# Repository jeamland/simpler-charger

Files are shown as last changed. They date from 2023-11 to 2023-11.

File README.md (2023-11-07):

# A "Simpler"[^1] Charger

This is a two-port USB charger design based around the [Texas Instruments TPS25858-Q1](https://www.ti.com/product/TPS25858-Q1) controller. It's designed to be part of a larger project to build some charging infrastructure into a shelf, hence the terminal block connections rather than actual USB-C ports. Input power is intended to be 15V coming from a power brick and the intent is to have several of these providing something like 12 ports in total (so 6 completed boards).

A lot of the layout and component selection was "inspired" by [TI's Evaluation Kit](https://www.ti.com/tool/TPS25858Q1EVM-140) for this device, but I have deviated in a few places, mainly for cost reasons. I ~~hope~~think I've validated that these changes are ok.

Full KiCad files, including custom symbols and footprints, are in here along with datasheets, PDF versions of the schematic and PCB layout, and the bill of materials.

[^1]: The original design I made did the full USB-C thing up to 60W and required an actual microcontroller. I may still make that one but, well, I figured I should overcomplicate things in stages.

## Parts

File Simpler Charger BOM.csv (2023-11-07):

Reference | Value | Description | Manufacturer | Manufacturer Part No | Qty
C1, C2 | 1µF 6.3V | CAP CER 1UF 6.3V X7R 0603 | Samsung Electro-Mechanics | CL10B105KQ8NFNC | 2
C3, C15 | 2.2µF | CAP CER 2.2UF 16V X5R 0603 | Kyocera AVX | KGM15AR51C225MT | 2
C4 | 10µF 50V | CAP CER 10UF 50V X7R 1210 | Murata Electronics | GRM32ER71H106MA12L | 1
C5 | 100µF 35V | CAP ALUM 100UF 20% 35V RADIAL | Rubycon | 35ZLJ100M6.3X11 | 1
C6-C8 | 10µF 50V | CAP CER 10UF 50V X5R 1206 | Murata Electronics | GRT31CR61H106KE01L | 3
C9 | 0.1µF 50V | CAP CER 0.1UF 50V X7R 1206 | Samsung Electro-Mechanics | CL31B104KBCNFNC | 1
C10, C14, C16 | 0.1µF 50V | CAP CER 0.1UF 50V X7R 0603 | Samsung Electro-Mechanics | CL10B104KB8NFNC | 3
C11-C13 | 22µF 10V | CAP CER 22UF 10V X7R 0805 | Murata Electronics | GRM21BZ71A226ME15L | 3
J1 | POWER | TERM BLK 2P TOP ENTRY 2.5MM PCB | Phoenix Contact | 1770953 | 1
J2 | PORT_A | TERM BLK 6P TOP ENTRY 2.5MM PCB | Phoenix Contact | 1770995 | 1
J3 | PORT_B | TERM BLK 6P TOP ENTRY 2.5MM PCB | Phoenix Contact | 1770995 | 1
L1 | 1µH | FIXED IND 1UH 12A 10 MOHM SMD | Pulse Electronics | BMRA000606301R0MA1 | 1
L2 | 3.3µH | FIXED IND 3.3UH 20.2A 5.44 MOHM | Vishay Dale | IHLP5050FDER3R3M51 | 1
R1 | 49.9KΩ | RES SMD 49.9K OHM 1% 1/10W 0603 | Panasonic Electronic Components | ERJ-3EKF4992V | 1
R2 | 20KΩ | RES SMD 20K OHM 5% 1/10W 0603 | Vishay Dale | CRCW060320K0JNEA | 1
R3, R6 | 5.1KΩ | RES 5.1K OHM 5% 1/10W 0603 | Vishay Dale | CRCW06035K10JNEAC | 2
R4 | 15KΩ | RES SMD 15K OHM 0.5% 1/10W 0603 | YAGEO | RT0603DRE0715KL | 1
R5 | 100KΩ | RES SMD 100K OHM 1% 1/10W 0603 | Vishay Dale | CRCW0603100KFKEA | 1
TH1 | 470KΩ | THERM NTC 470KOHM 4500K 0603 | Murata Electronics | NCP18WM474E03RB | 1
U1 | TPS25858-Q1 | Dual 3A USB Type-C Charging Ports Controller with Programmable Current Limit and Thermal Management, RPQ0025A (VQFN-25) | Texas Instruments | TPS25858QRPQRQ1 | 1

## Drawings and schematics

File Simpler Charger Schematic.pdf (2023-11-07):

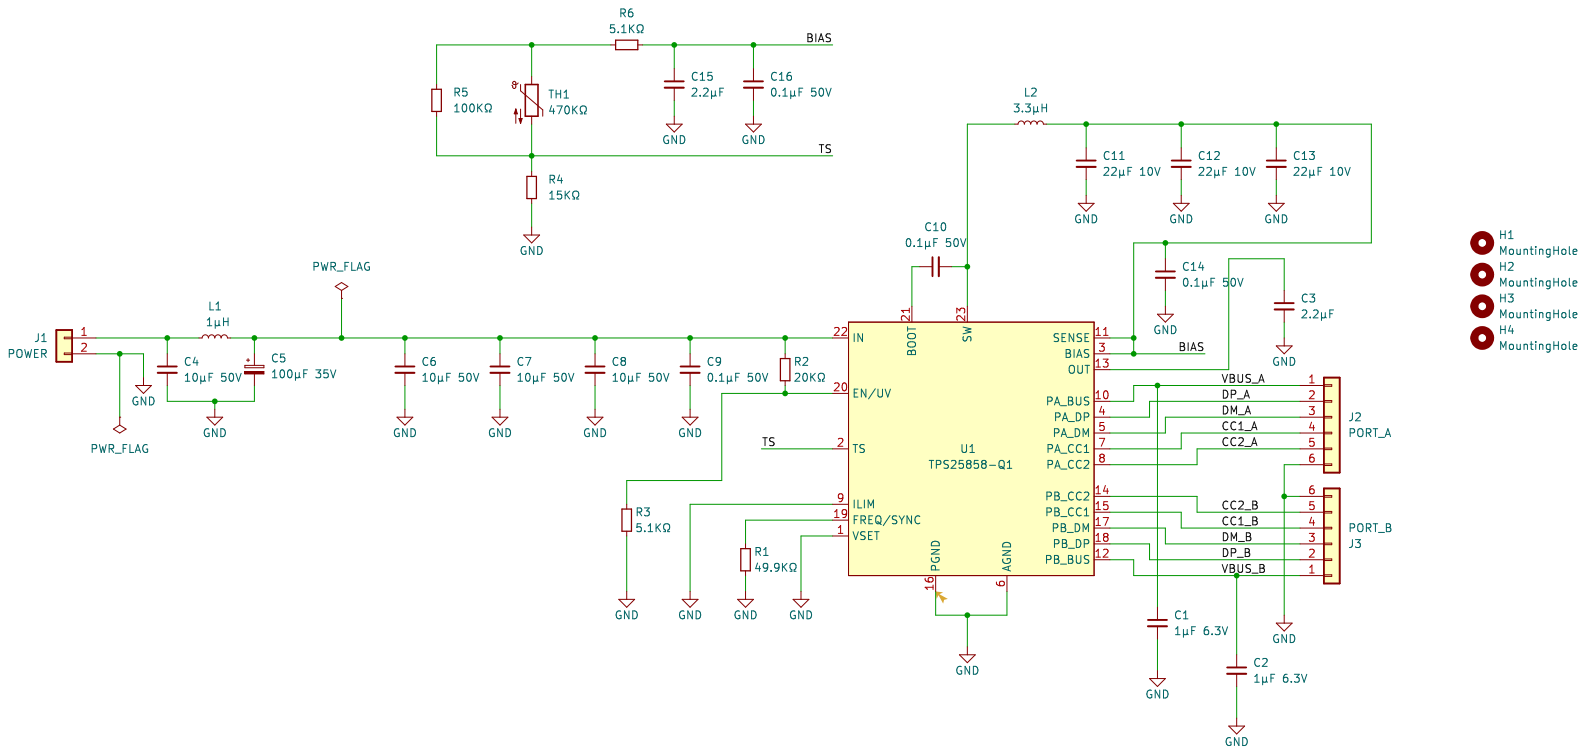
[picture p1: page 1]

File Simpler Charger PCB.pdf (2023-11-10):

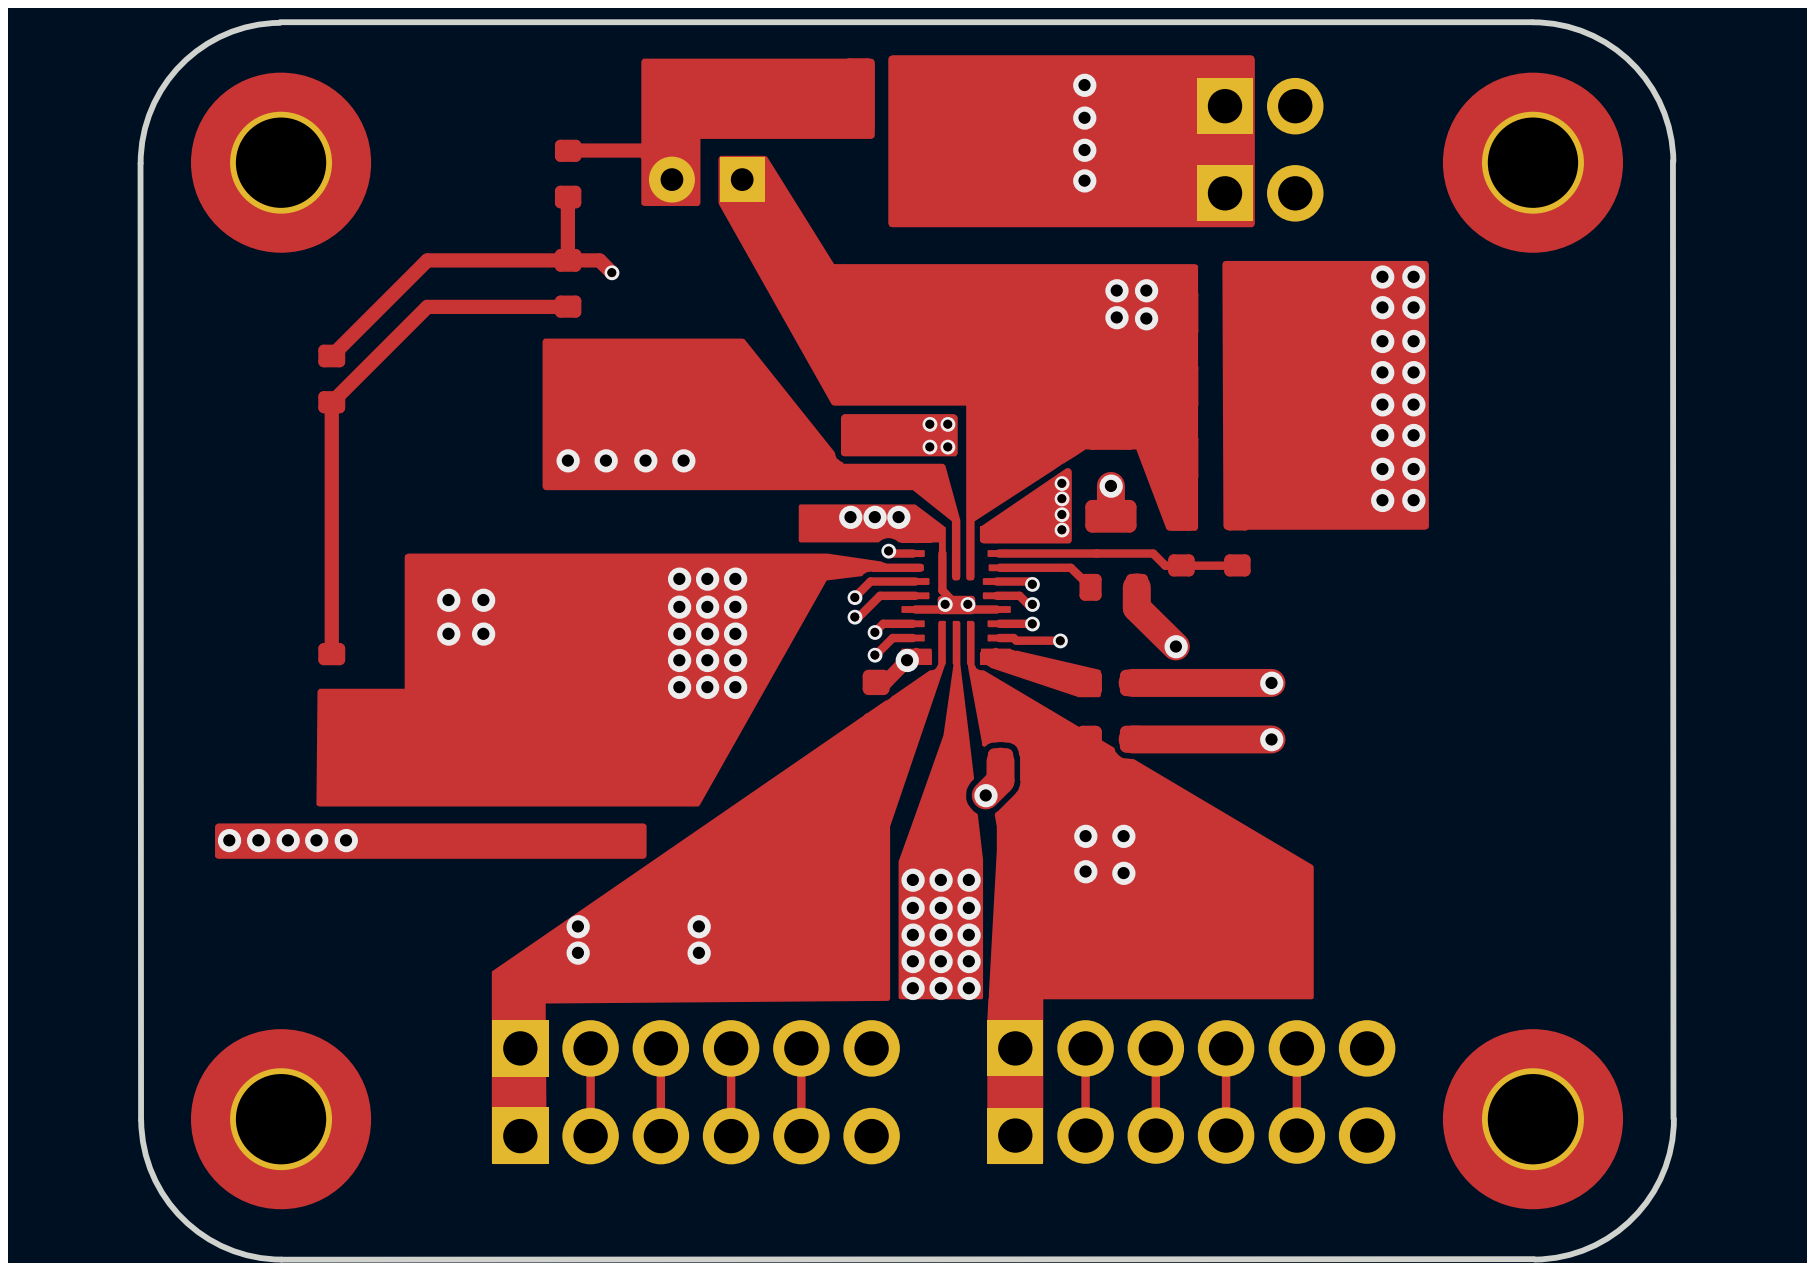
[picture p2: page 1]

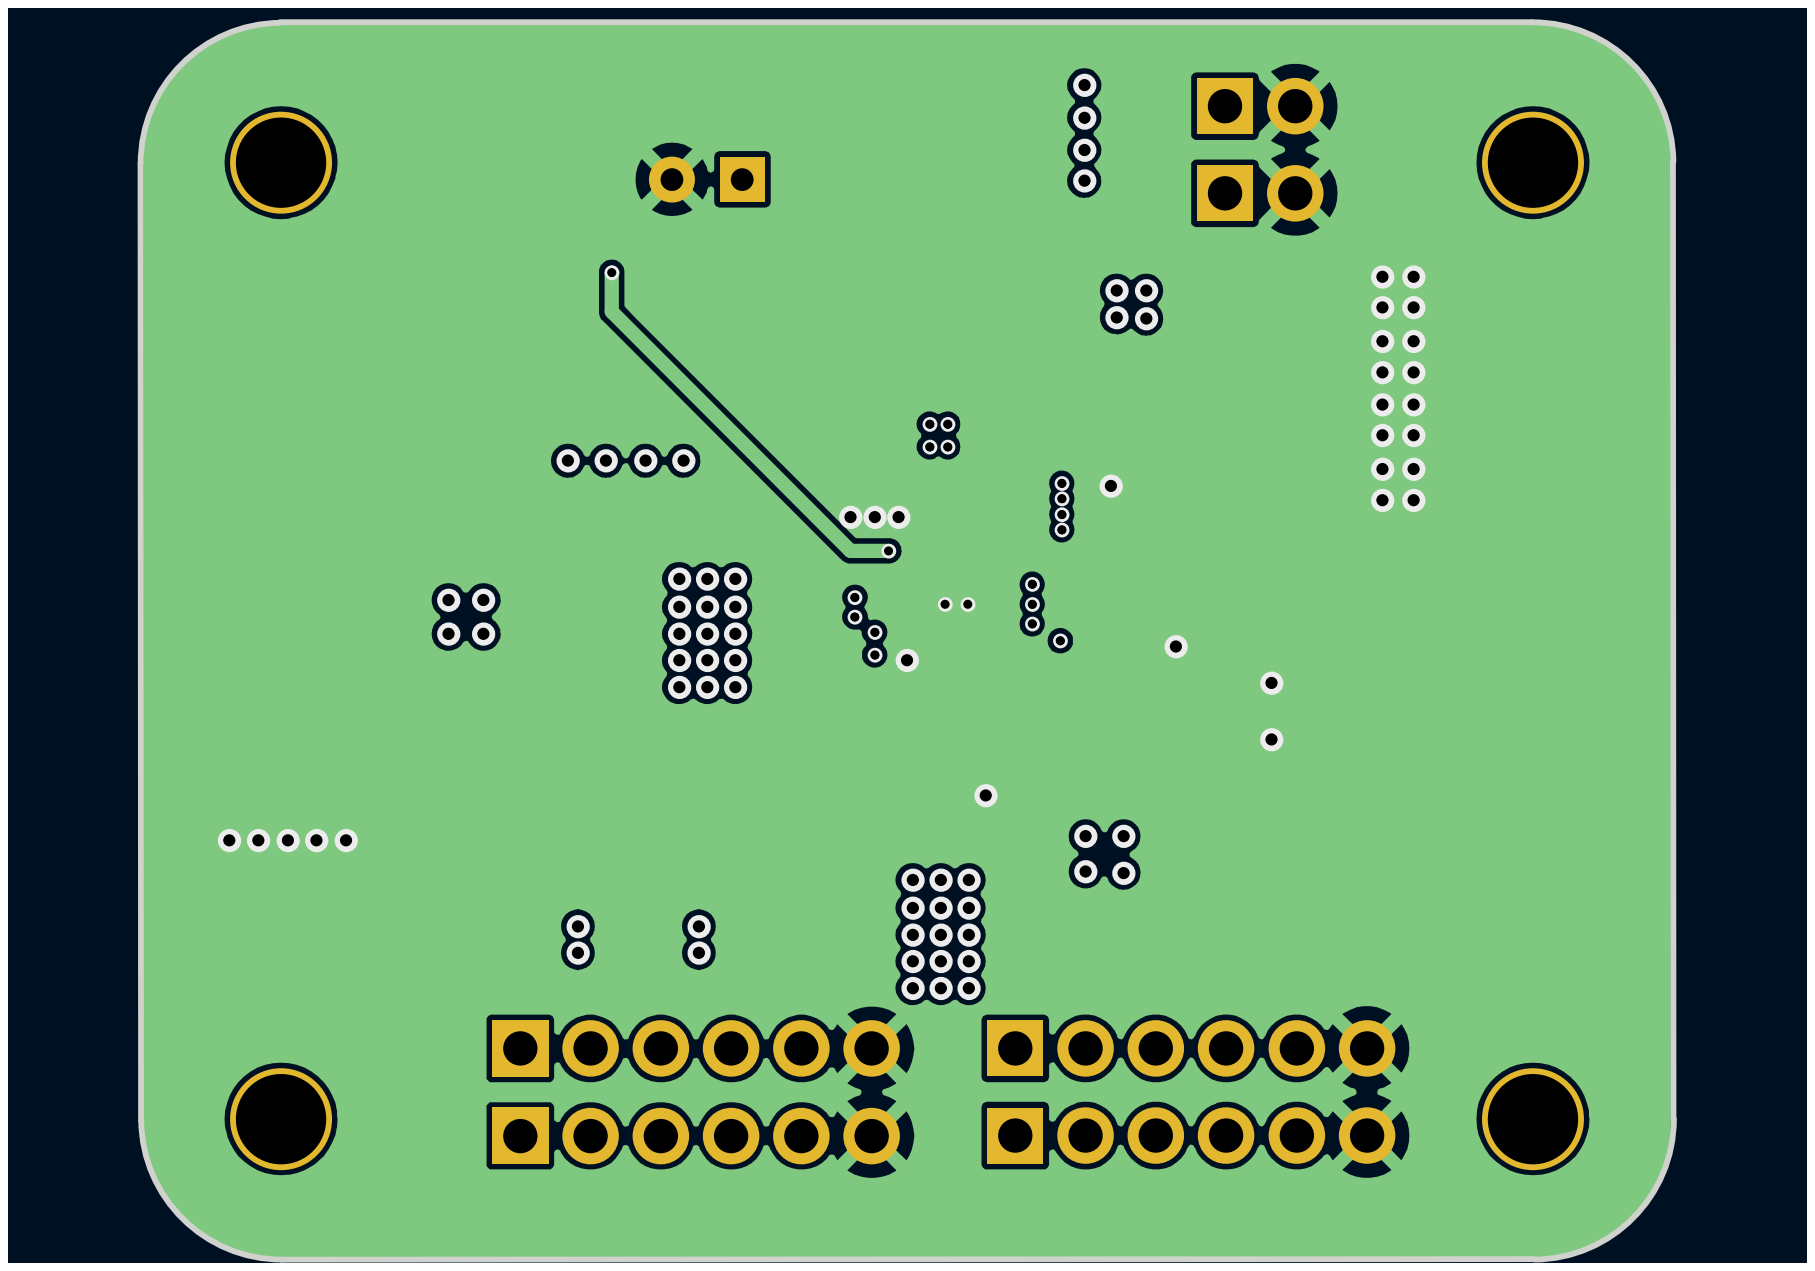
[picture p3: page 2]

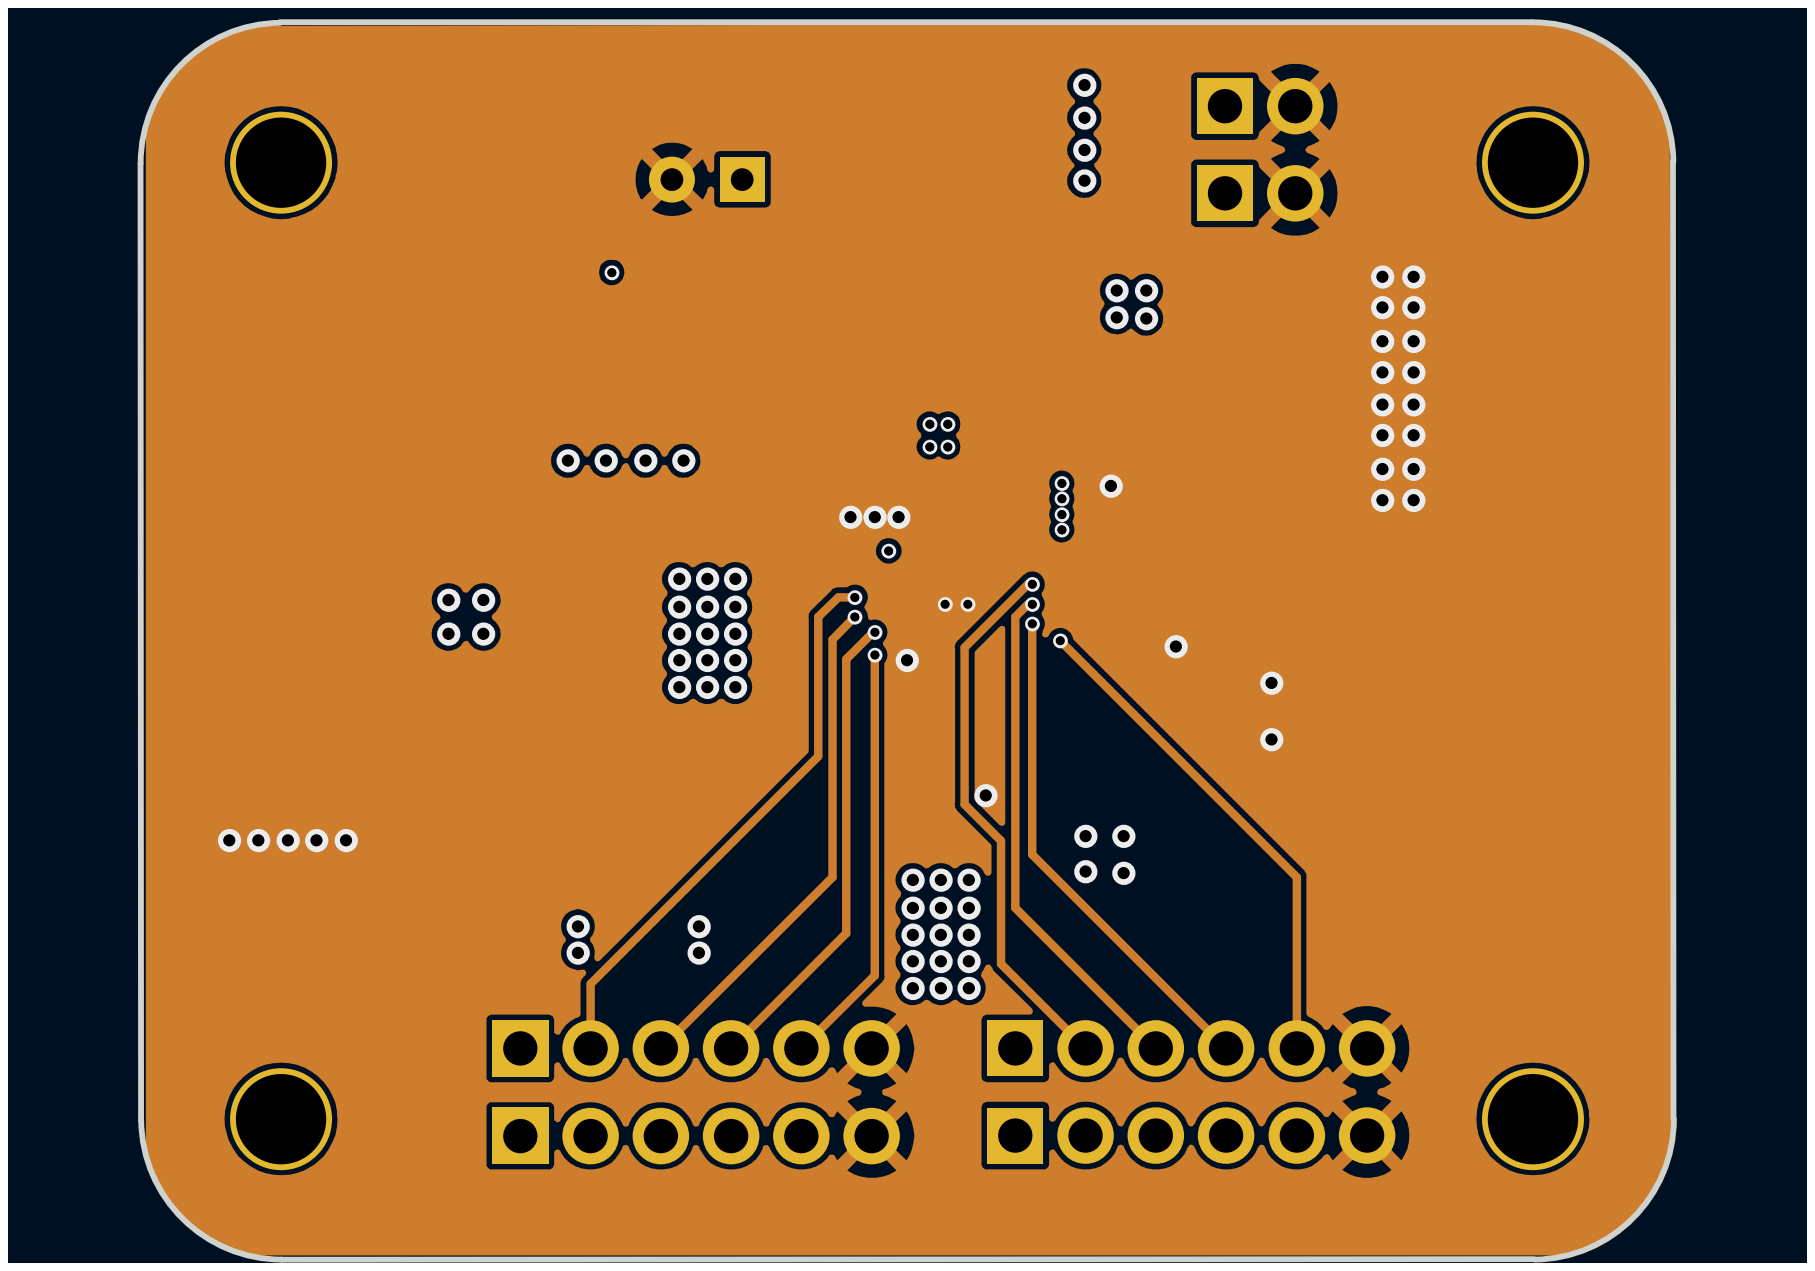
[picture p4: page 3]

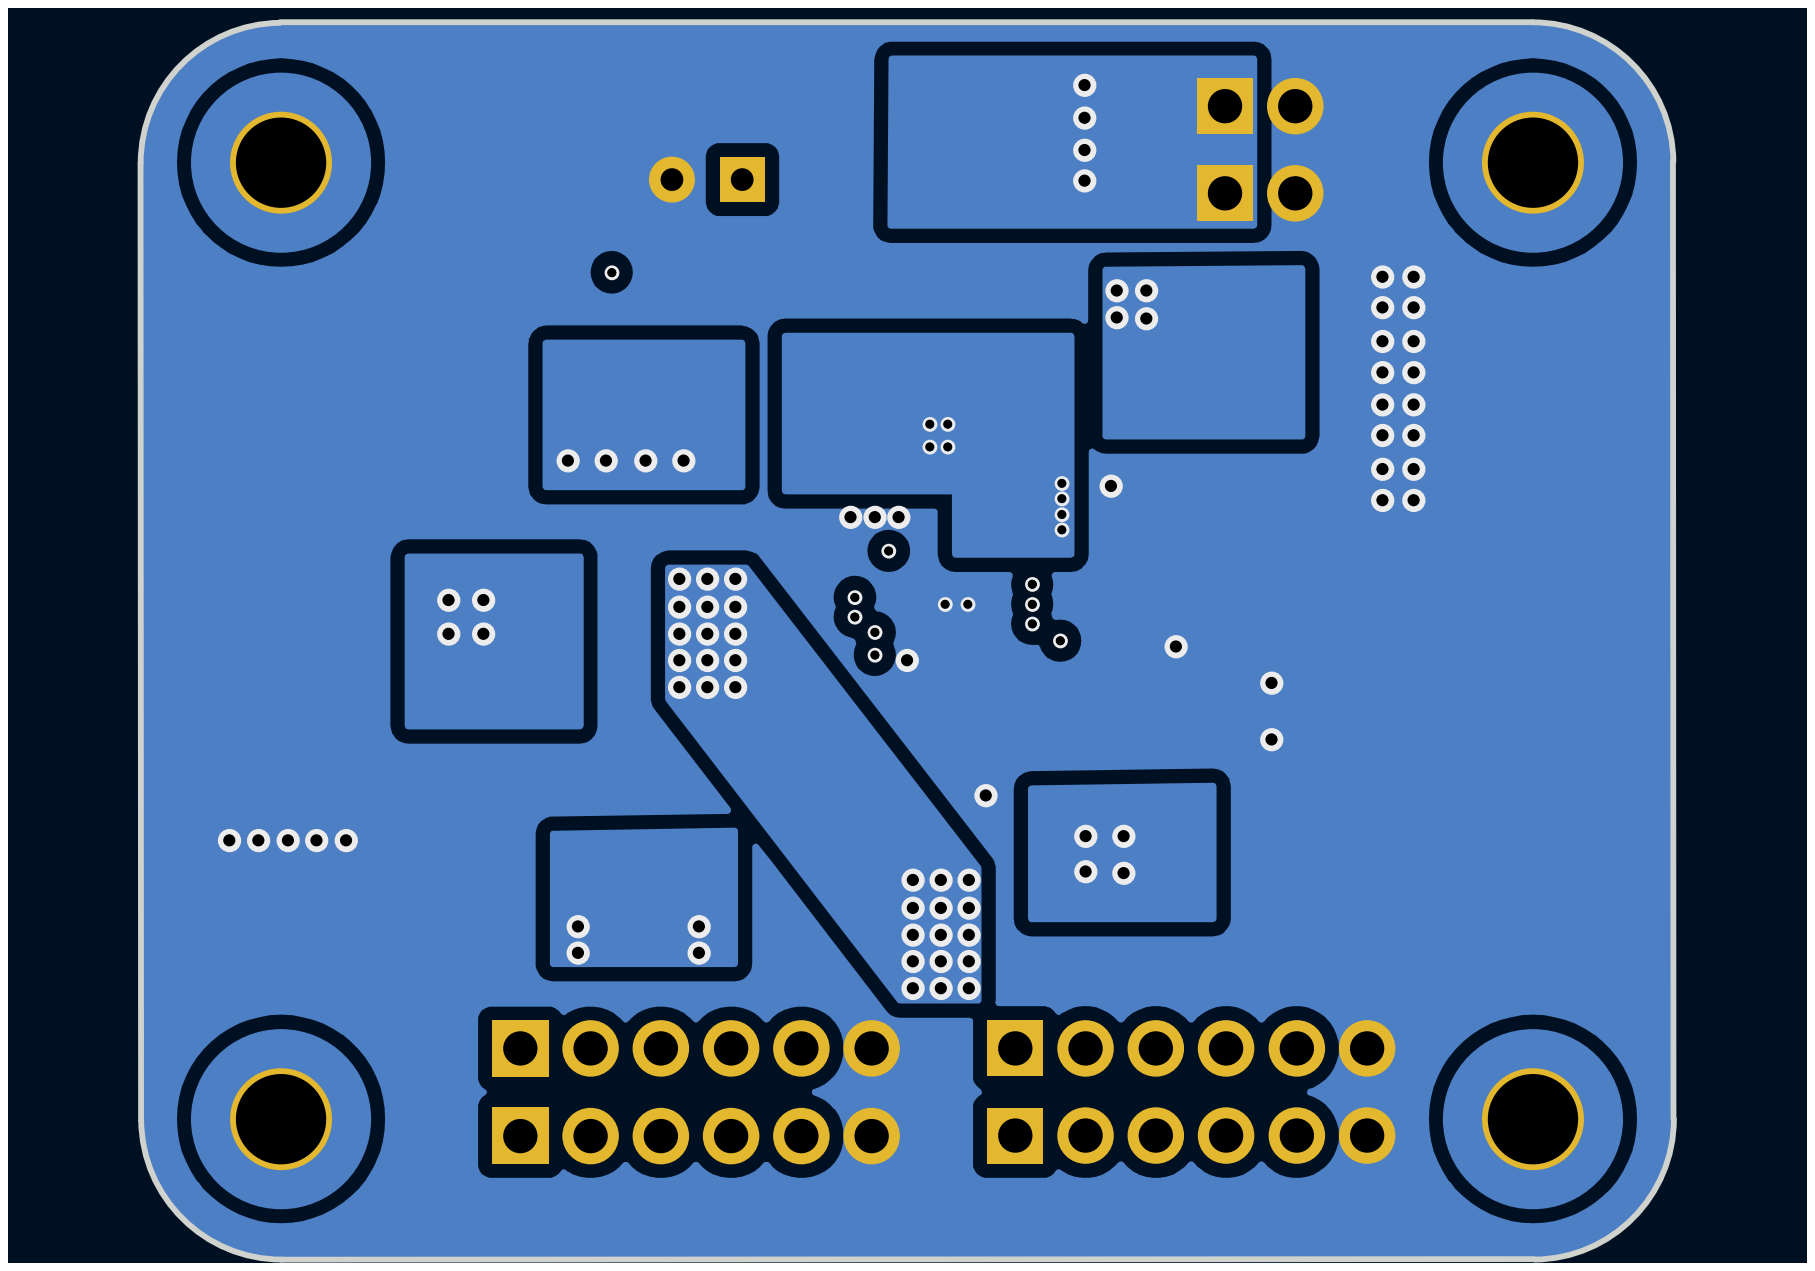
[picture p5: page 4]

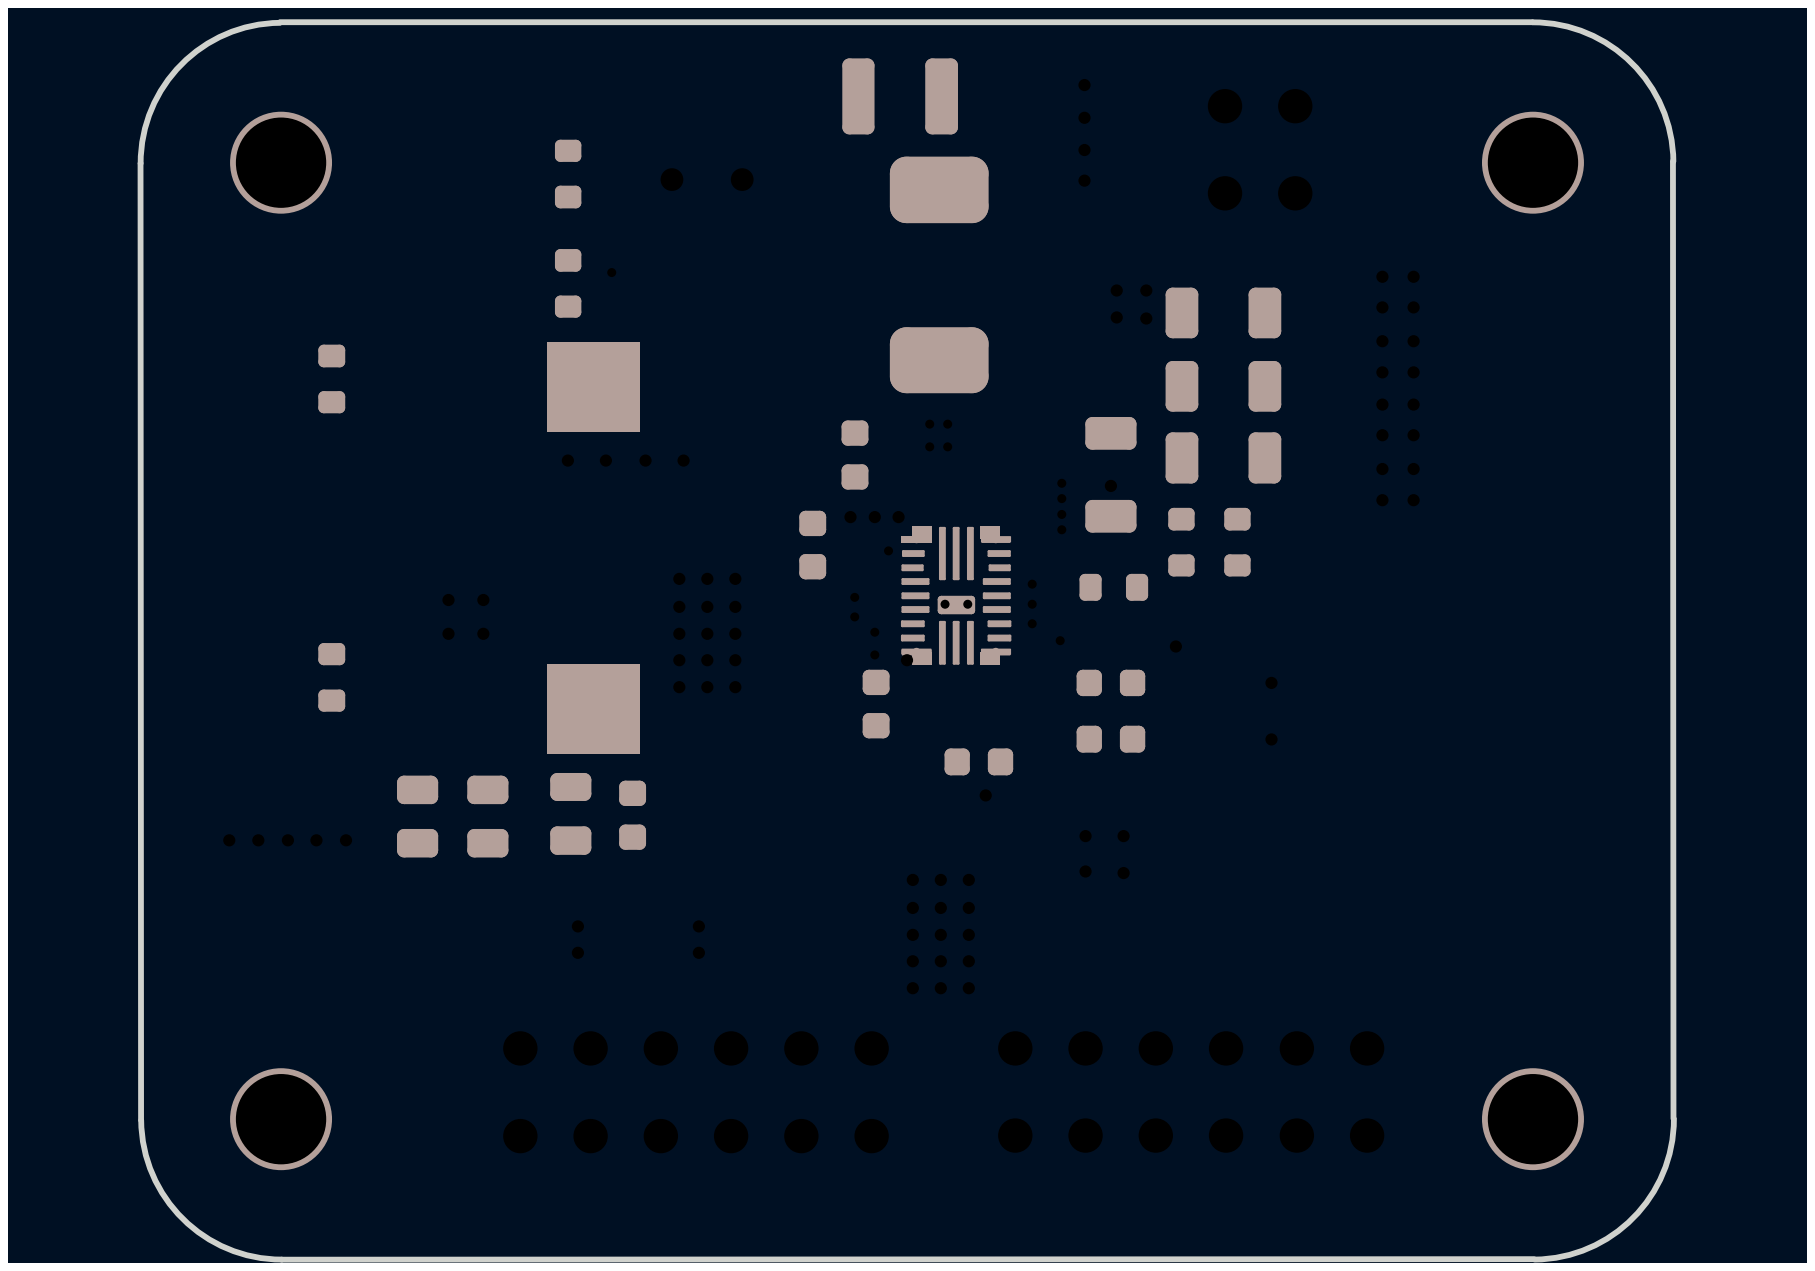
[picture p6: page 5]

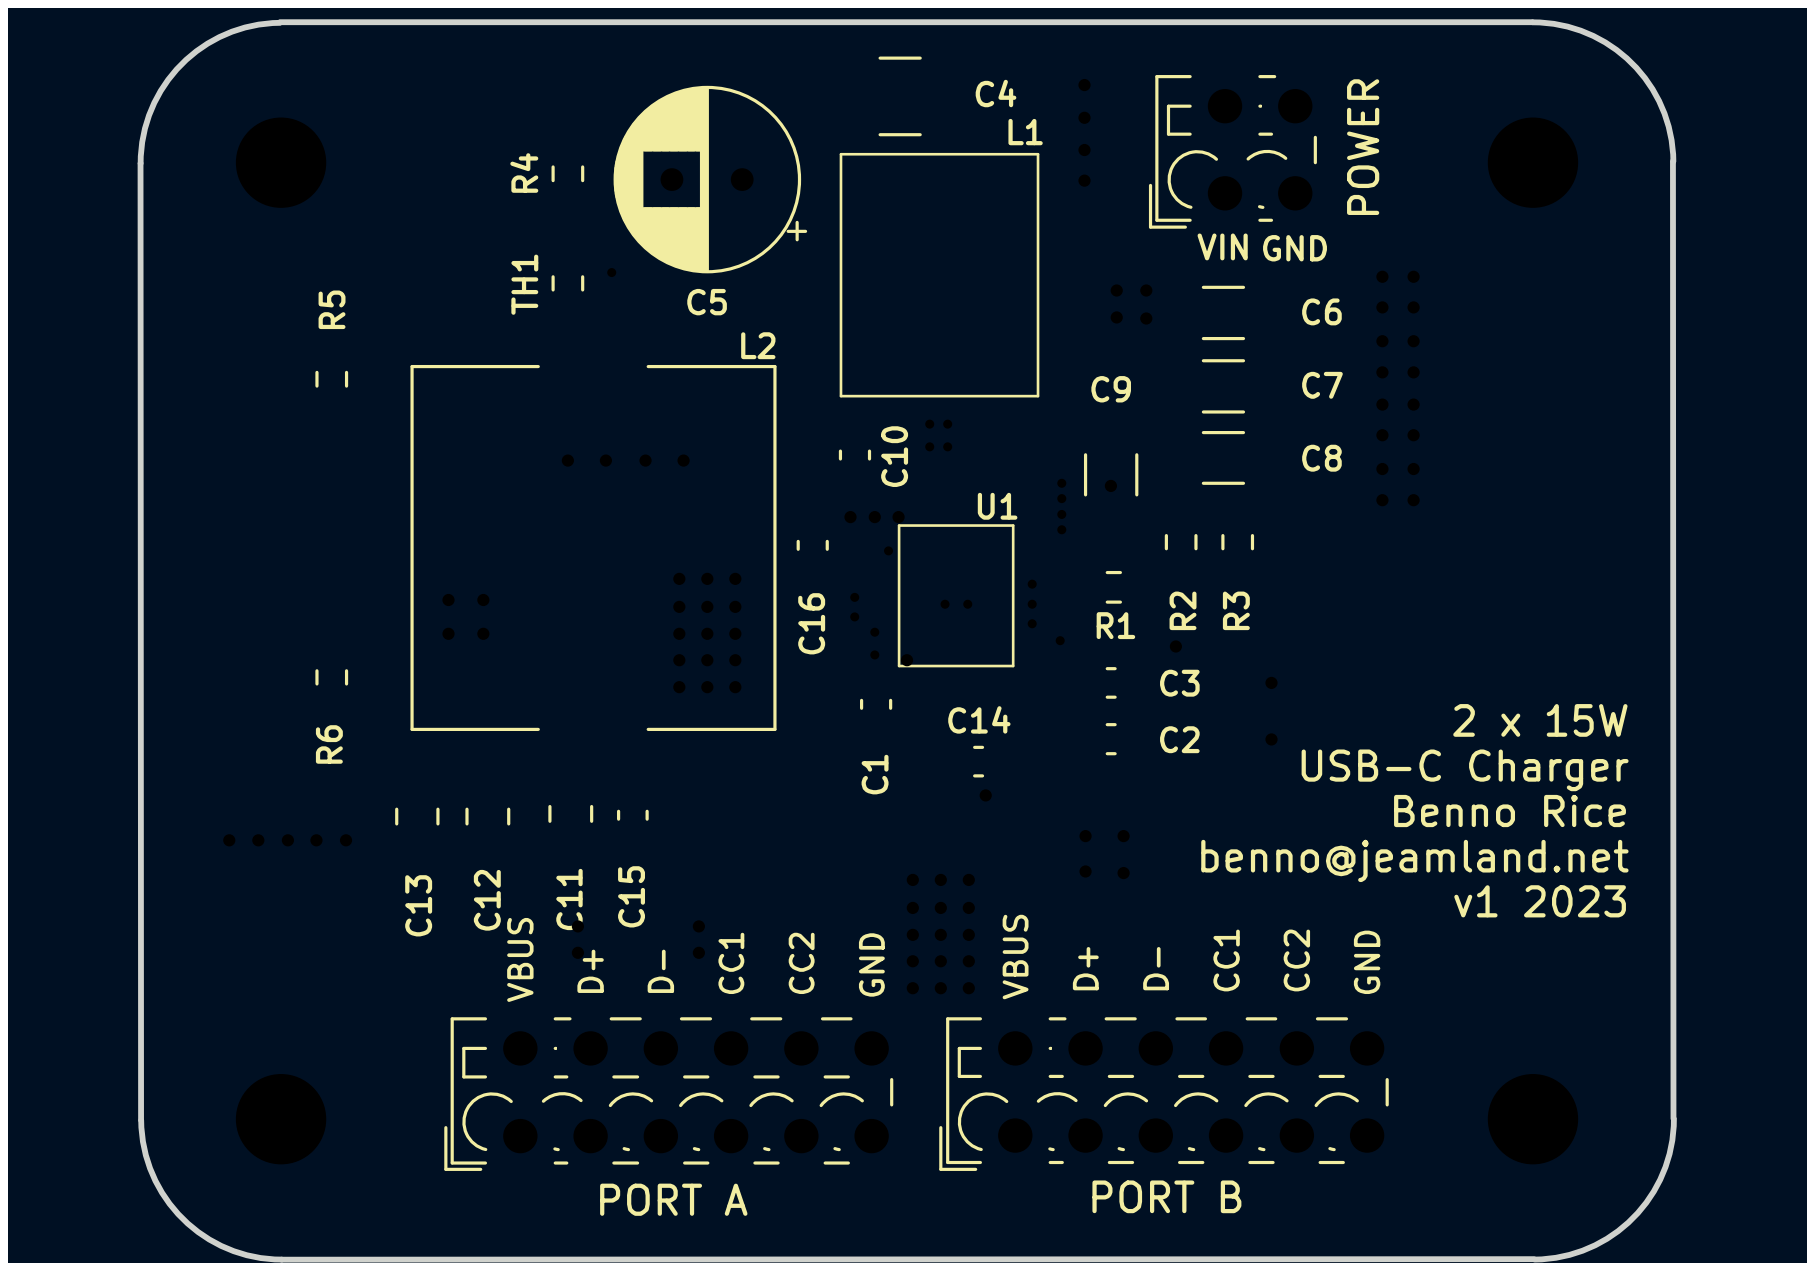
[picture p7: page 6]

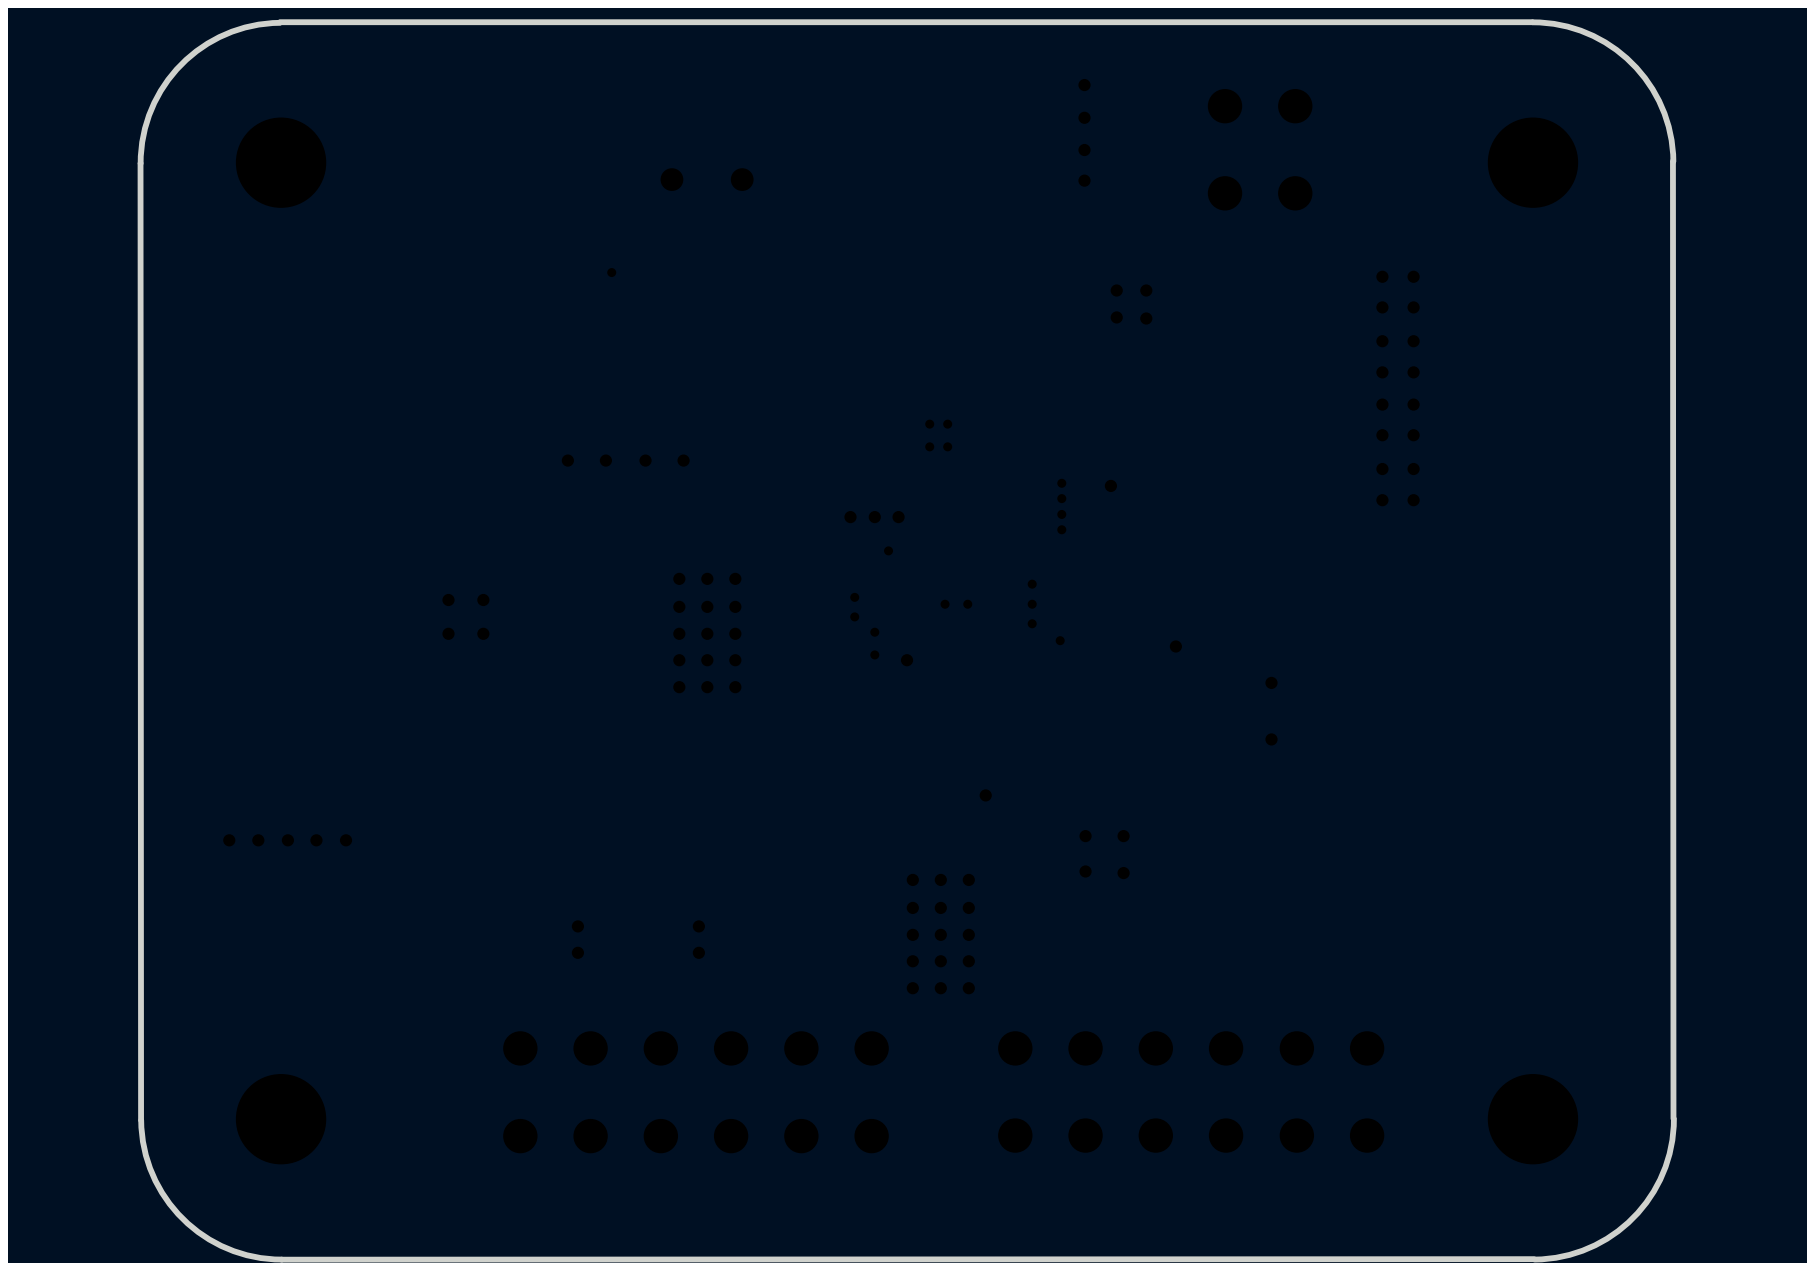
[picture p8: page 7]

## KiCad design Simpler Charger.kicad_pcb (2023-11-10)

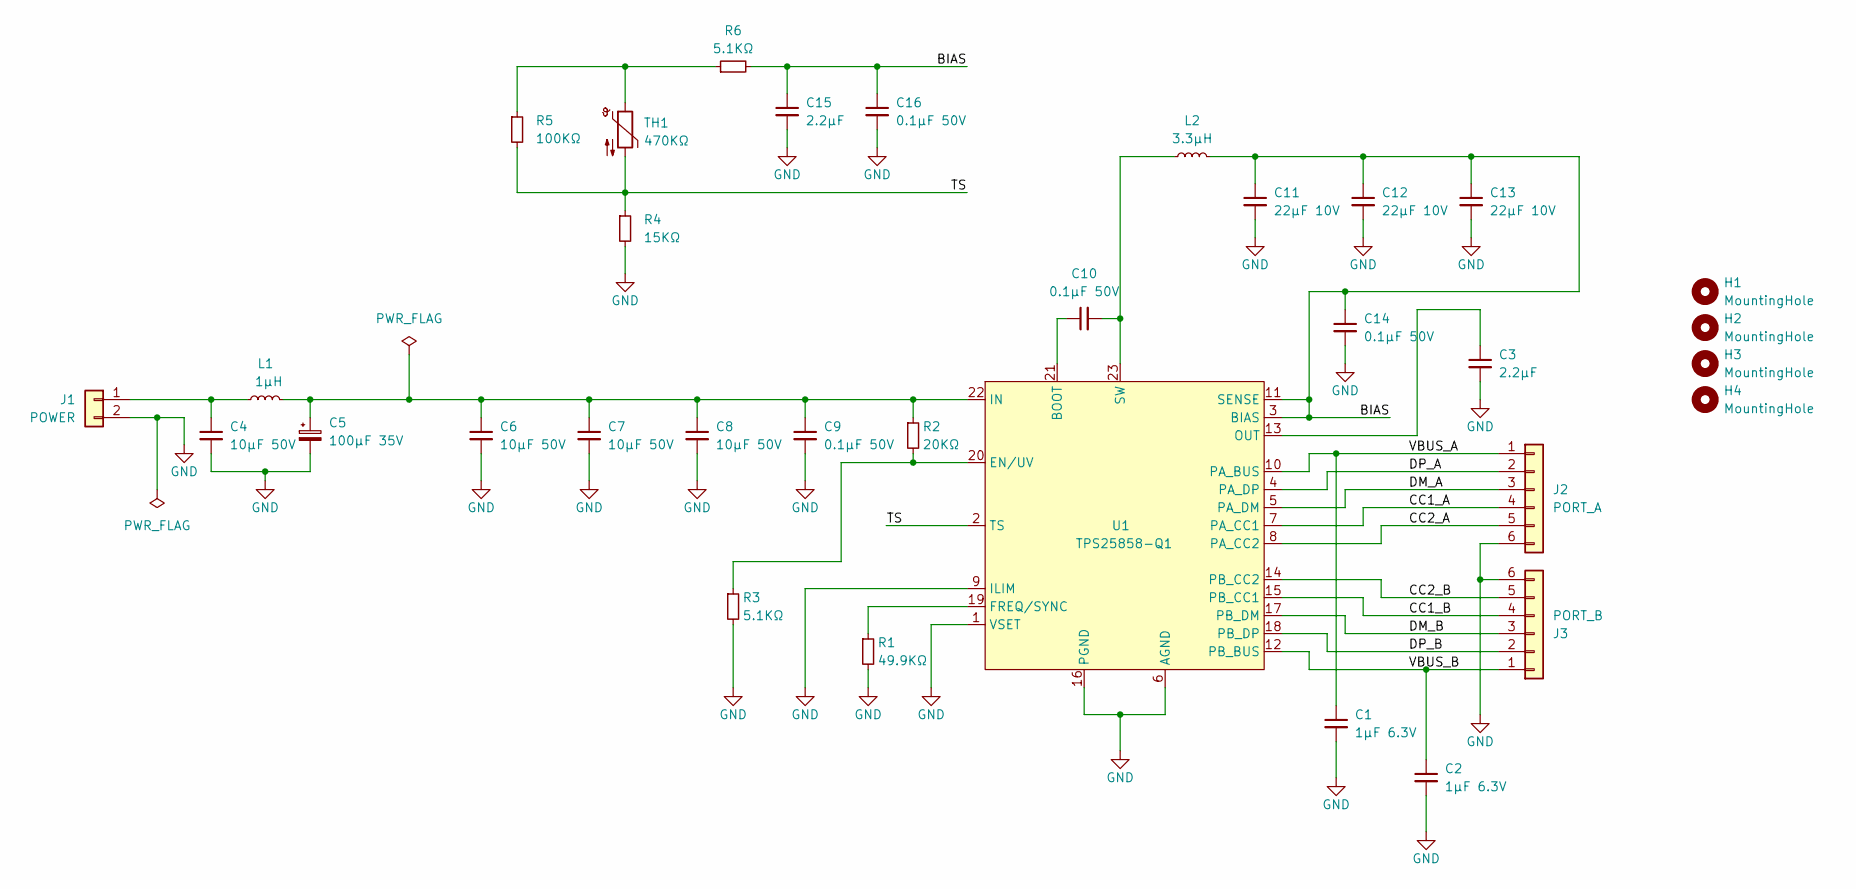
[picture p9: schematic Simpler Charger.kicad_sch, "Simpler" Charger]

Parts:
C1, C2: 1µF 6.3V; C_0603_1608Metric; Manufacturer Part No CL10B105KQ8NFNC
C3, C15: 2.2µF; C_0603_1608Metric; Manufacturer Part No KGM15AR51C225MT
C4: 10µF 50V; C_1210_3225Metric; Manufacturer Part No GRM32ER71H106MA12L
C5: 100µF 35V; CP_Radial_D6.3mm_P2.50mm; Manufacturer Part No 35ZLJ100M6.3X11
C6, C7, C8: 10µF 50V; C_1206_3216Metric; Manufacturer Part No GRT31CR61H106KE01L
C9: 0.1µF 50V; C_1206_3216Metric; Manufacturer Part No CL31B104KBCNFNC
C10, C14, C16: 0.1µF 50V; C_0603_1608Metric; Manufacturer Part No CL10B104KB8NFNC
C11, C12, C13: 22µF 10V; C_0805_2012Metric; Manufacturer Part No GRM21BZ71A226ME15L
H1, H2, H3, H4: MountingHole; MountingHole_3.2mm_M3_Pad_TopBottom
J1: POWER; TerminalBlock_Phoenix_PTSM-0,5-2-2.5-V-THR_1x02_P2.50mm_Ver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; Manufacturer Part No 1770953
J2: PORT_A; TerminalBlock_Phoenix_PTSM-0,5-6-2.5-V-THR_1x06_P2.50mm_Ver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; Manufacturer Part No 1770995
J3: PORT_B; TerminalBlock_Phoenix_PTSM-0,5-6-2.5-V-THR_1x06_P2.50mm_Ver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; Manufacturer Part No 1770995
L1: 1µH; BMRx00060630; Manufacturer Part No BMRA000606301R0MA1
L2: 3.3µH; L_Vishay_IHLP-5050; Manufacturer Part No IHLP5050FDER3R3M51
R1: 49.9KΩ; R_0603_1608Metric; Manufacturer Part No ERJ-3EKF4992V
R2: 20KΩ; R_0603_1608Metric; Manufacturer Part No CRCW060320K0JNEA
R3, R6: 5.1KΩ; R_0603_1608Metric; Manufacturer Part No CRCW06035K10JNEAC
R4: 15KΩ; R_0603_1608Metric; Manufacturer Part No RT0603DRE0715KL
R5: 100KΩ; R_0603_1608Metric; Manufacturer Part No CRCW0603100KFKEA
TH1: 470KΩ; R_0603_1608Metric; Manufacturer Part No NCP18WM474E03RB
U1: TPS25858-Q1; Manufacturer Part No TPS25858QRPQRQ1

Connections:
/BIAS: C11.1, C12.1, C13.1, C14.1, C15.1, C16.1, L2.2, R6.2, U1.3 (BIAS), U1.11 (SENSE)
/CC1_A: J2.4, U1.7 (PA_CC1)
/CC1_B: J3.4, U1.15 (PB_CC1)
/CC2_A: J2.5, U1.8 (PA_CC2)
/CC2_B: J3.5, U1.14 (PB_CC2)
/DM_A: J2.3, U1.5 (PA_DM)
/DM_B: J3.3, U1.17 (PB_DM)
/DP_A: J2.2, U1.4 (PA_DP)
/DP_B: J3.2, U1.18 (PB_DP)
/TS: R4.1, R5.2, TH1.2, U1.2 (TS)
/VBUS_A: C1.1, J2.1, U1.10 (PA_BUS)
/VBUS_B: C2.1, J3.1, U1.12 (PB_BUS)
GND: C1.2, C2.2, C3.2, C4.2, C5.2, C6.2, C7.2, C8.2, C9.2, C11.2, C12.2, C13.2, C14.2, C15.2, C16.2, J1.2, J2.6, J3.6, R1.2, R3.2, R4.2, U1.1 (VSET), U1.6 (AGND), U1.9 (ILIM), U1.16 (PGND), U1.24 (PGND), U1.25 (PGND)
unnamed: C4.1, J1.1, L1.1
unnamed: R5.1, R6.1, TH1.1
unnamed: C10.1, U1.21 (BOOT)
unnamed: R2.2, R3.1, U1.20 (EN/UV)
unnamed: R1.1, U1.19 (FREQ/SYNC)
unnamed: C5.1, C6.1, C7.1, C8.1, C9.1, L1.2, R2.1, U1.22 (IN)
unnamed: C3.1, U1.13 (OUT)
unnamed: C10.2, L2.1, U1.23 (SW)

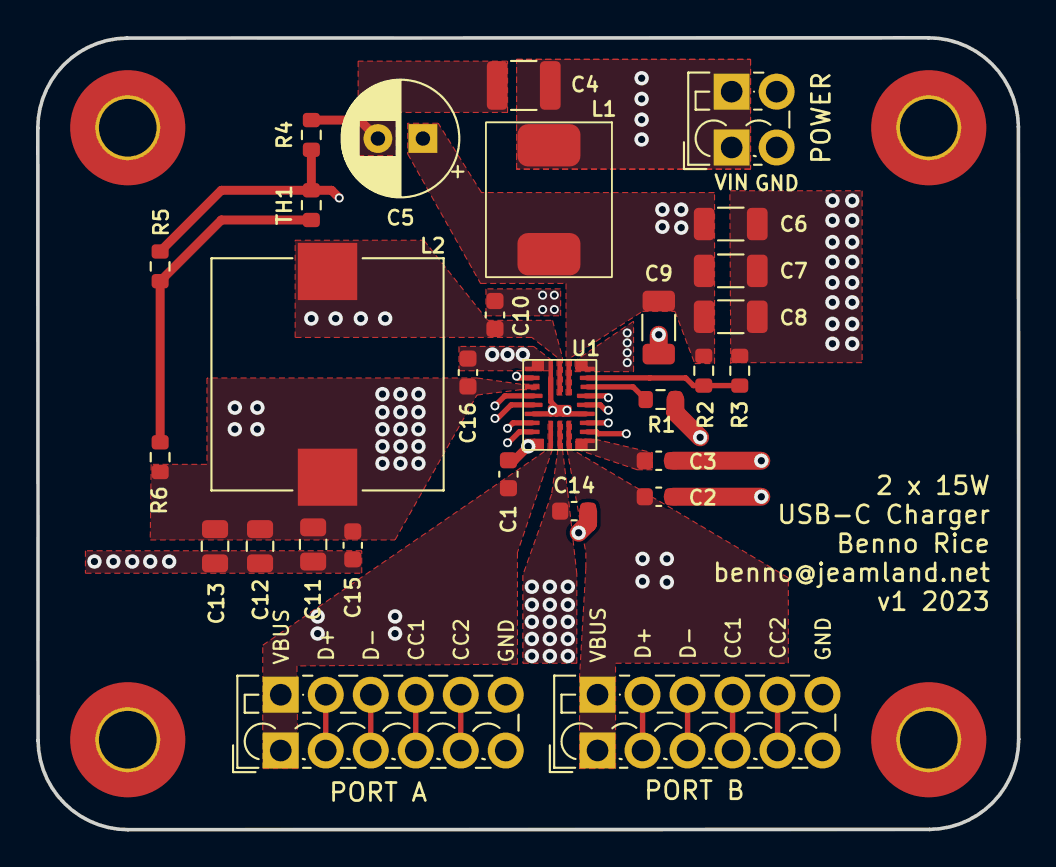
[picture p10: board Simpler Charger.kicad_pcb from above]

Board: 4 copper layers, 54.5 x 44.0 mm, 33 parts (0 on the bottom side), 21 nets.

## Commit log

2023-11-07 KiCad files
    [Simpler Charger.kicad_pcb, Simpler Charger.kicad_sch]
2023-11-07 Schematic PDF
2023-11-07 PCB PDF (one layer per page)
2023-11-07 Move things around so L2's loop is shorter
    [Simpler Charger.kicad_pcb, Simpler Charger.kicad_sch]
2023-11-08 Hopefully better thermals for the high-current bits
    [Simpler Charger.kicad_pcb]
2023-11-09 Adjust silkscreen text sizes, put mounting holes in paste layer
    [Simpler Charger.kicad_pcb]
2023-11-10 Round corners, shuffle some silkscreens
    [Simpler Charger.kicad_pcb]
2023-11-10 No idea.
    [Simpler Charger.kicad_pcb]
